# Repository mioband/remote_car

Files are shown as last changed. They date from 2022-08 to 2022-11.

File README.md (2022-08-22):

# remote_car
Данный репозиторий содержит код для модуля машинки для управления с браслета
## Ветки
В данном репозитории две основные ветки:
### main
Главная ветка со стабильной версией ПО. Здесь всегда должен быть чистый и рабочий код, а также вся документация. 
### develop
Ветка разработки. Здесь находятся тестовые и разрабатываемые версии кода.

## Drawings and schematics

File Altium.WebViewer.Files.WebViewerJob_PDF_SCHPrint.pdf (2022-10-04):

1K R8

# 0.1uFR⁹

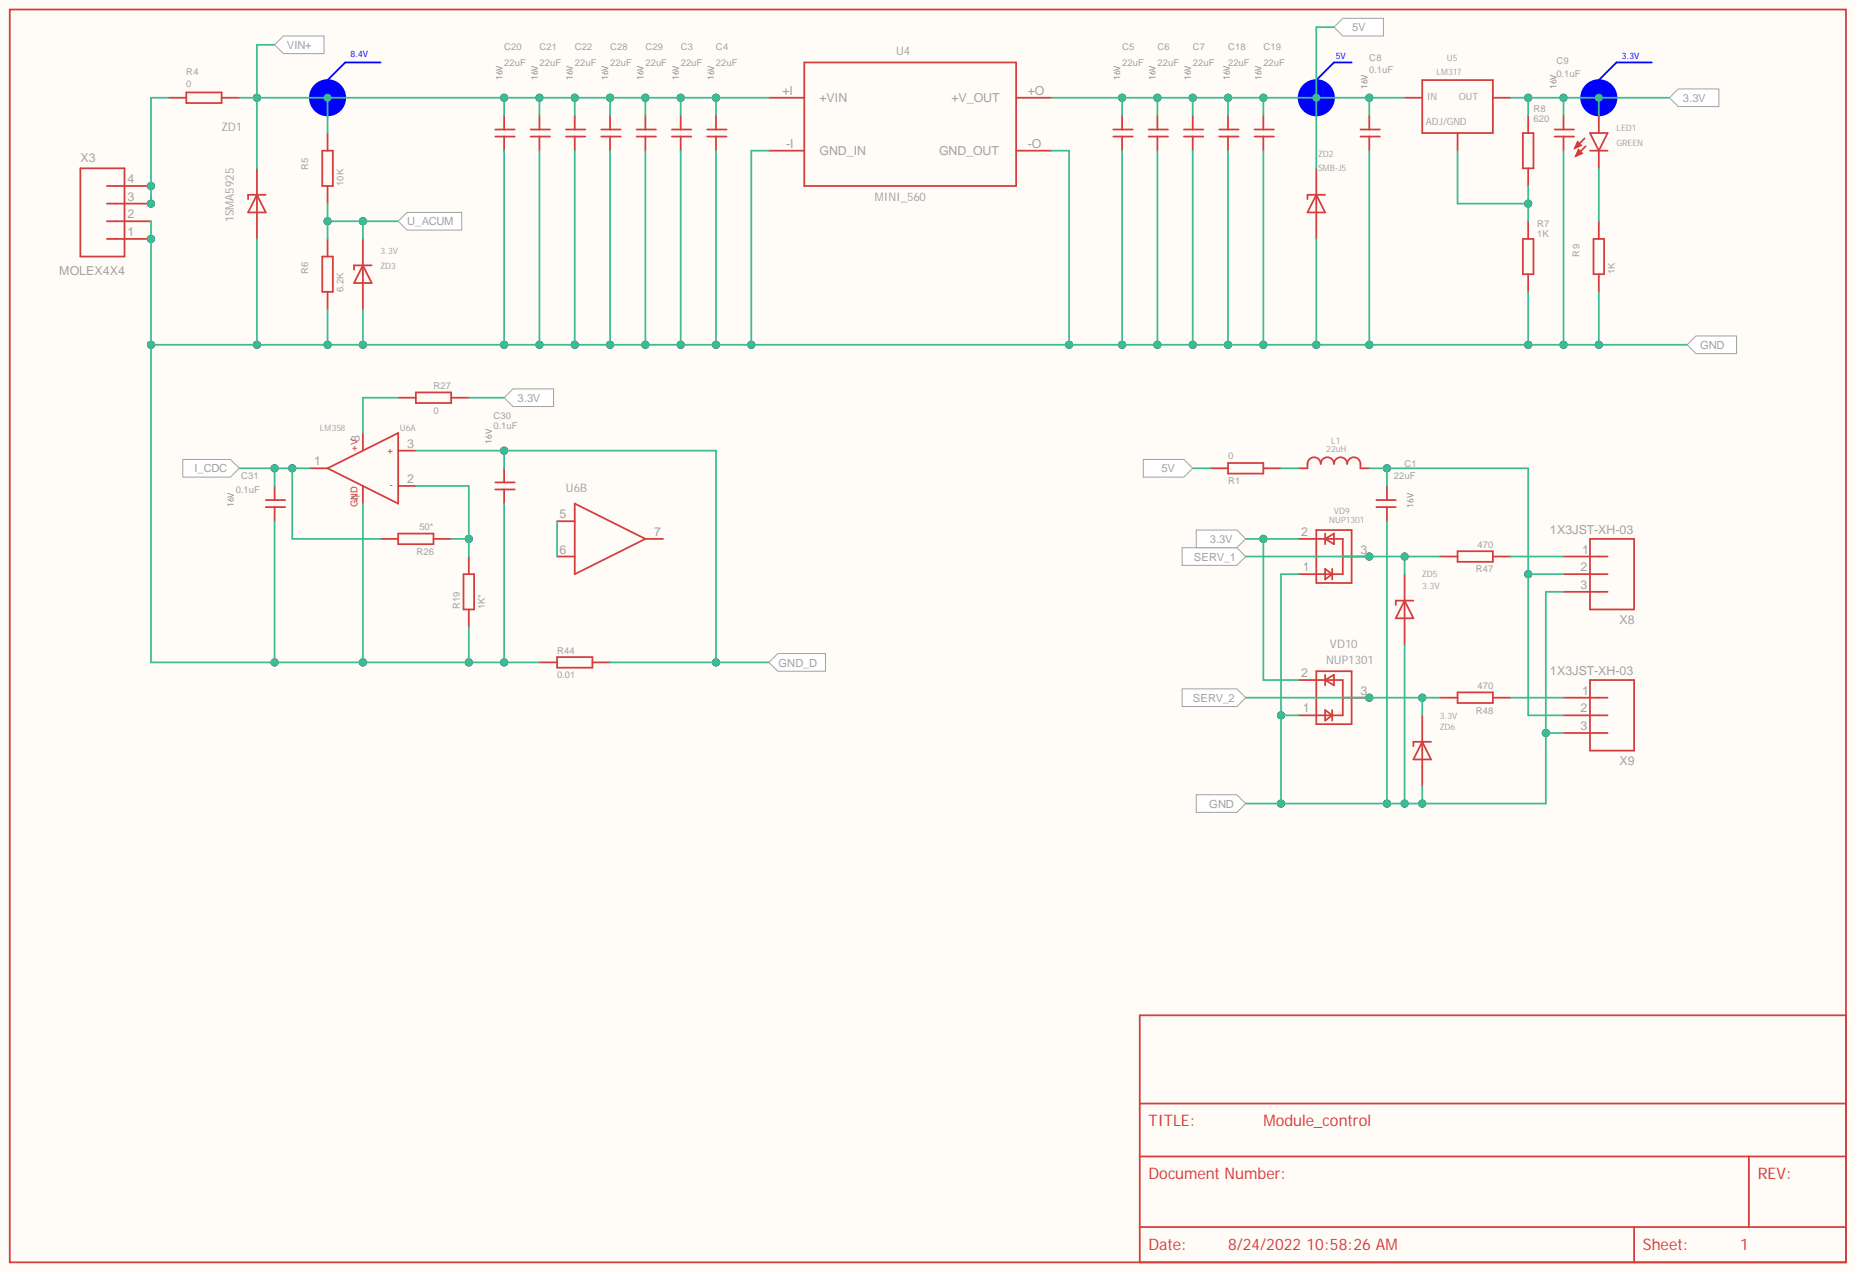
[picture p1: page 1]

: | REV:

Date: 8/24/2022 10:58:26 AM | Sheet: 1

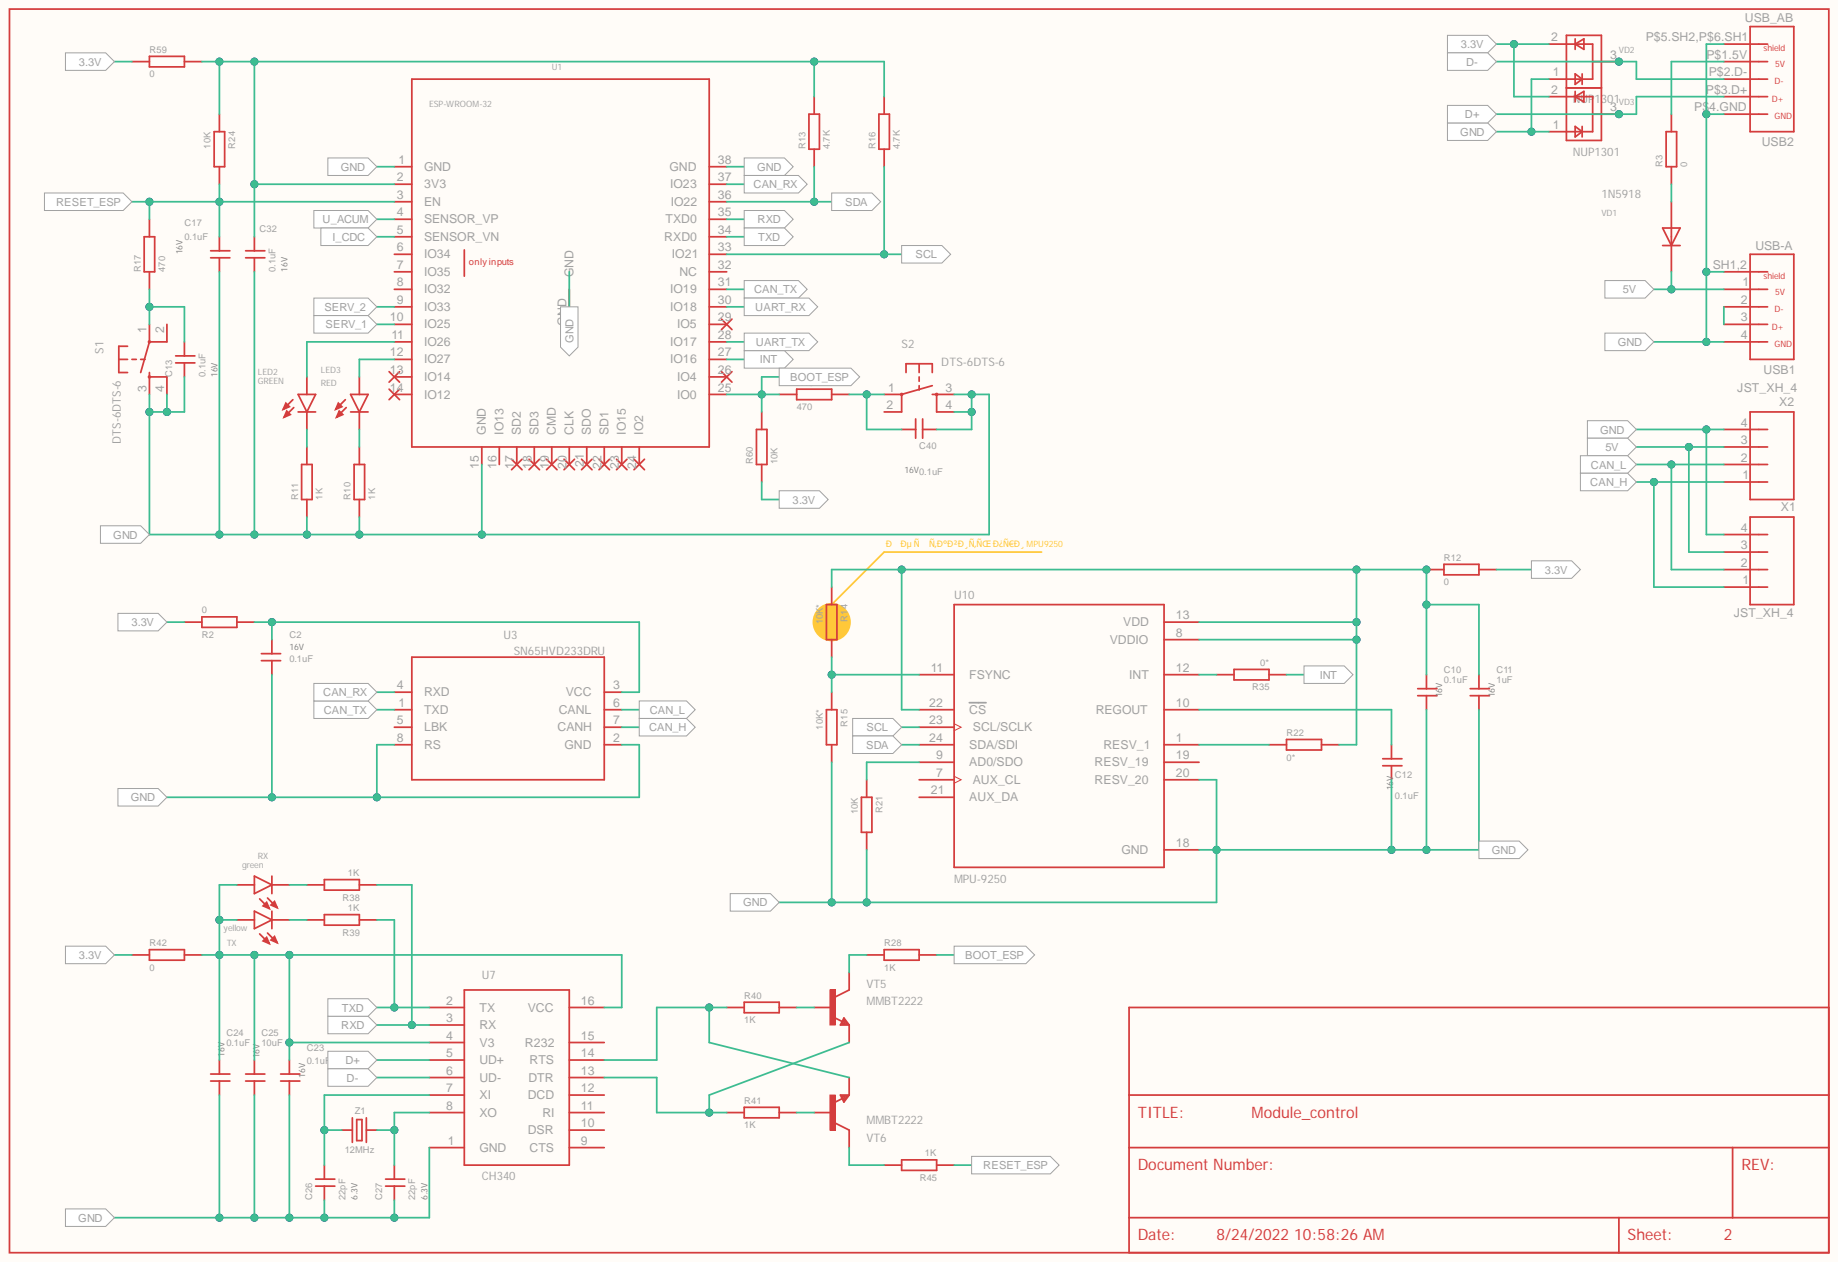
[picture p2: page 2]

IO2 24 IO15 23 SD1 22 SDO 21 CLK 20 GND GND

Document Number: | REV:

Date: 8/24/2022 10:58:26 AM | Sheet: 2

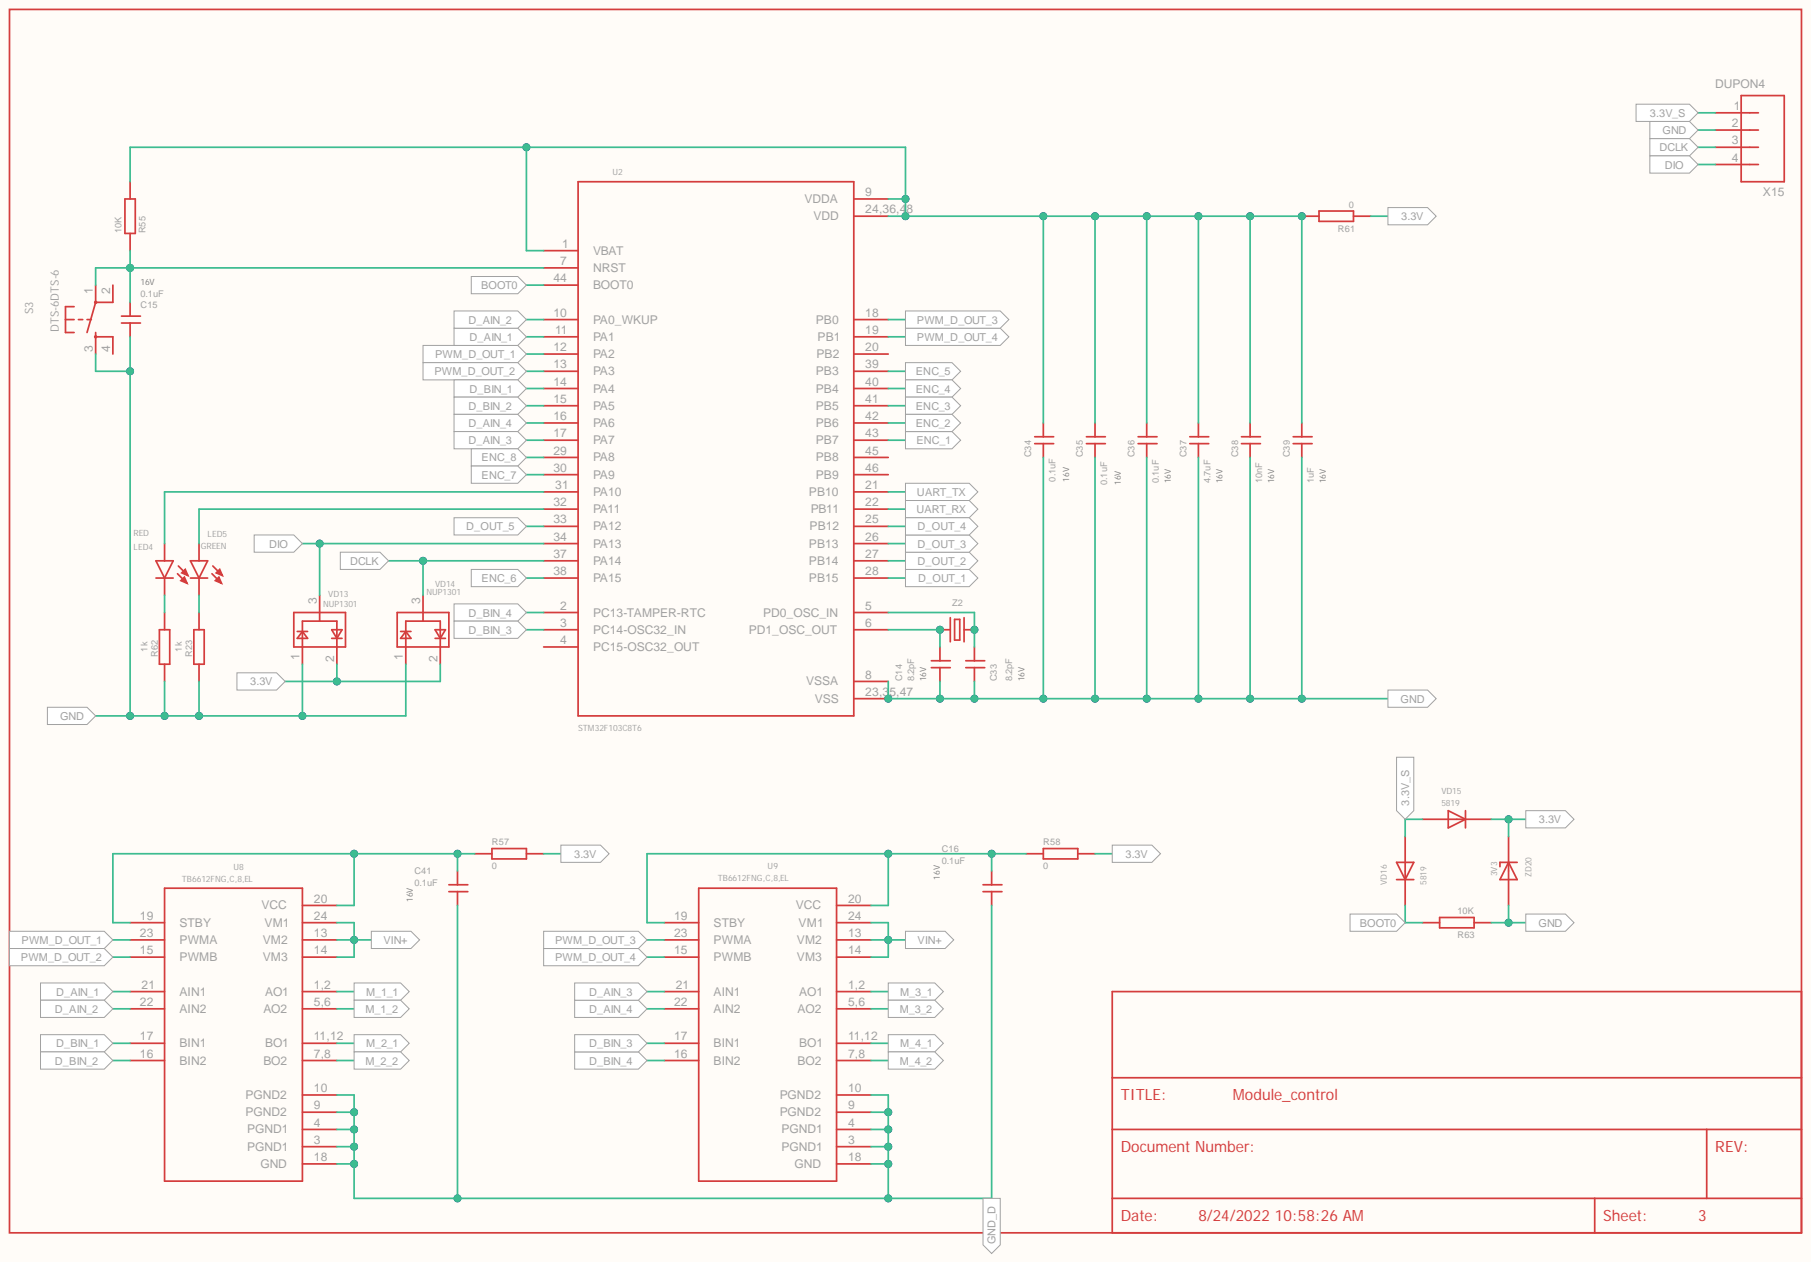
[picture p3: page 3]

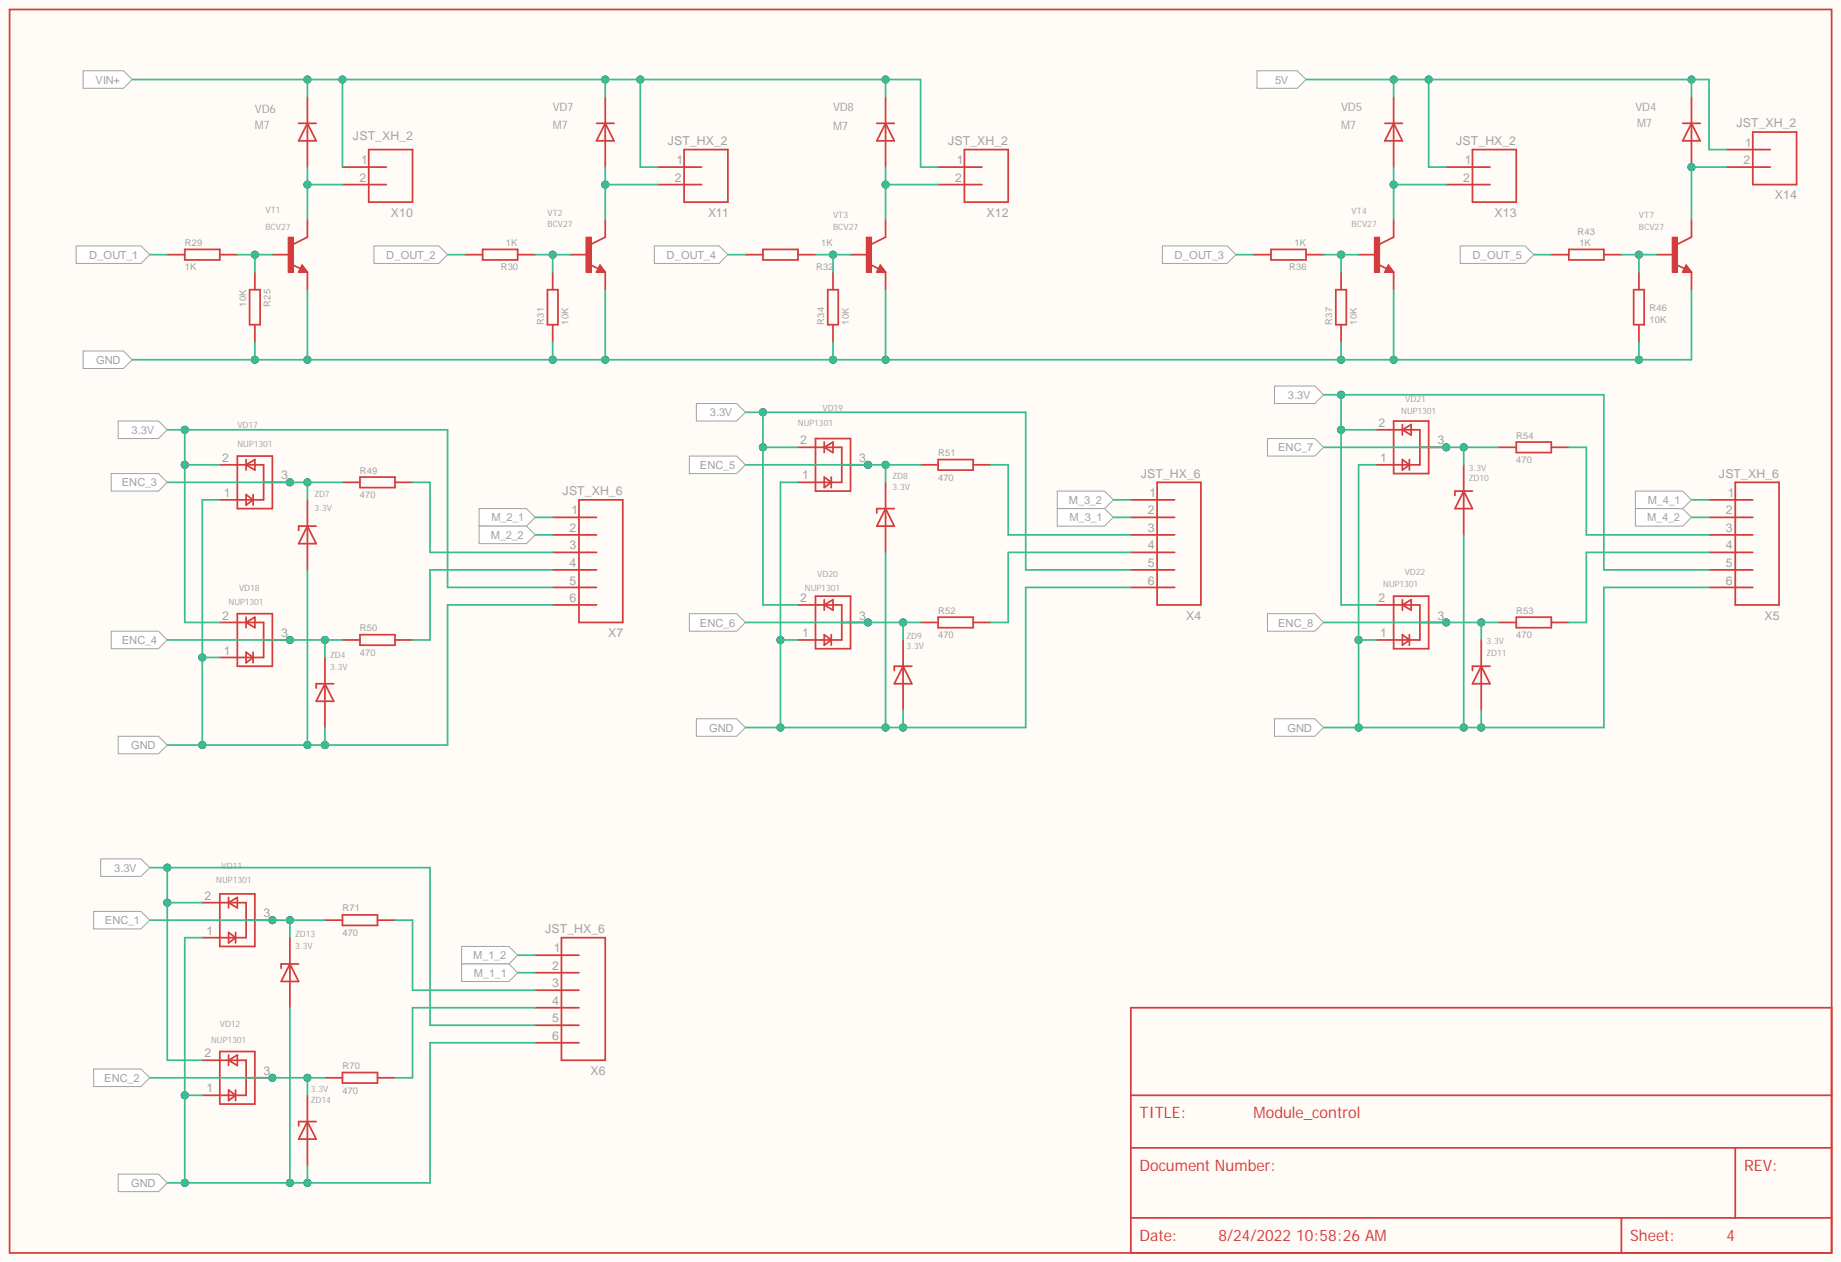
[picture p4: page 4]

Document Number: | REV:

Date: 8/24/2022 10:58:26 AM | Sheet: 4

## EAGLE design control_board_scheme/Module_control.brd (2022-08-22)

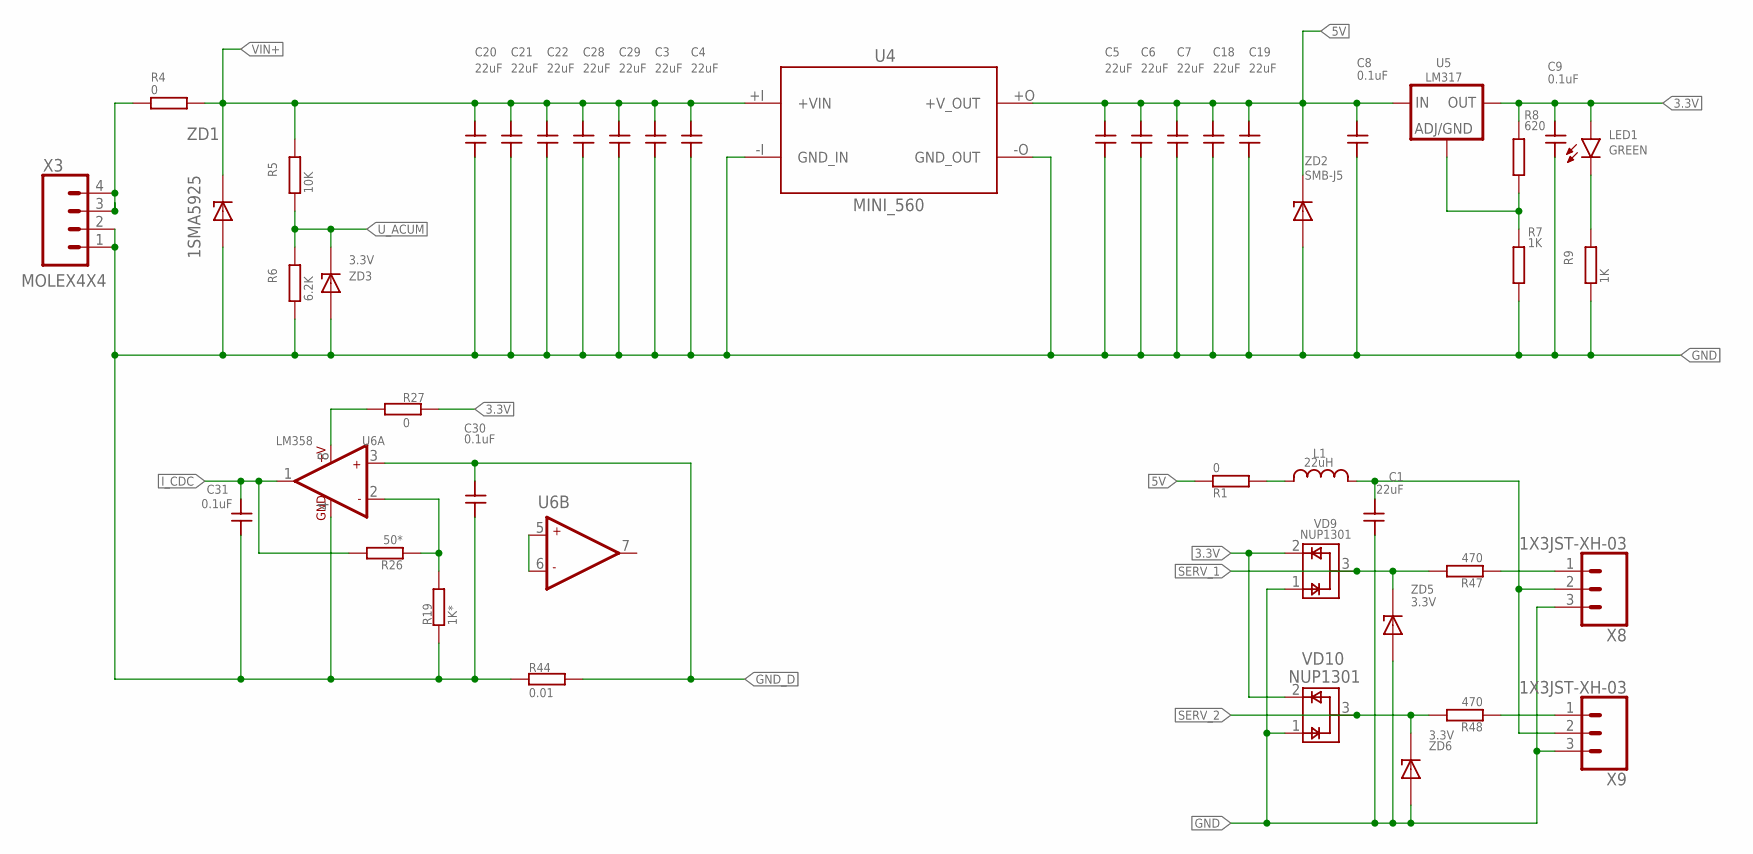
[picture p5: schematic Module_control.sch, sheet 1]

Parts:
C1, C3, C4, C5, C6, C7, C18, C19, C20, C21, C22, C28, C29: 22uF; 1206; VOLTAGE 16V
C8, C9, C30, C31: 0.1uF; 0603; VOLTAGE 16V
L1: 22uH; 0420CDMC
LED1: GREEN; 1608
R1, R27: 0; 0603
R4: 0; 2512
R5: 10K; 0603
R6: 6.2K; 0603
R7, R9: 1K; 0603
R8: 620; 0603
R19: 1K*; 0603
R26: 50*; 0603
R44: 0.01; 1206
R47, R48: 470; 0603
U4: MINI_560; MINI560_OTB
U5: LM317; D-PAK
U6: LM358; SOIC-8
VD9, VD10: NUP1301; SOT23
X3: MOLEX4X4; MOLEX-2X2U
X8, X9: 1X3JST-XH-03; JST-XH-03
ZD1: 1SMA5925; SMB
ZD2: SMB-J5; SMB
ZD3, ZD5, ZD6: 3.3V; MINIMELF

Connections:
3.3V: C9.P$2, LED1.P$2 (A), R8.P$2, R27.P$2, U5.4 (OUT), VD9.2 (VCC), VD10.2 (VCC); also elsewhere on the board
5: L1.2, R1.P$2
5V: C5.P$2, C6.P$2, C7.P$2, C8.P$2, C18.P$2, C19.P$2, R1.P$1, U4.+O (+V_OUT), U5.3 (IN), ZD2.C; also elsewhere on the board
GND: C1.P$1, C3.P$1, C4.P$1, C5.P$1, C6.P$1, C7.P$1, C8.P$1, C9.P$1, C18.P$1, C19.P$1, C20.P$1, C21.P$1, C22.P$1, C28.P$1, C29.P$1, C30.P$1, C31.P$1, R6.P$1, R7.P$2, R9.P$1, R19.P$1, R44.P$1, U4.-I (GND_IN), U4.-O (GND_OUT), U6.4 (GND), VD9.1 (GND), VD10.1 (GND), X3.1, X3.2, X8.3, X9.3, ZD1.A, ZD2.A, ZD3.A, ZD5.A, ZD6.A; also elsewhere on the board
GND_D: C30.P$2, R44.P$2, U6.3 (+IN1); also elsewhere on the board
I_CDC: C31.P$2, R26.P$2, U6.1 (OUT1); also elsewhere on the board
unnamed: R48.P$1, X9.1
unnamed: R7.P$1, R8.P$1, U5.1 (ADJ/GND)
unnamed: LED1.P$1 (C), R9.P$2
unnamed: R4.1, X3.3, X3.4
unnamed: R47.P$1, X8.1
unnamed: R19.P$2, R26.P$1, U6.2 (-IN1)
unnamed: U6.5 (+IN2), U6.6 (-IN2)
SERV_1: R47.P$2, VD9.3 (I/O), ZD5.C; also elsewhere on the board
SERV_2: R48.P$2, VD10.3 (I/O), ZD6.C; also elsewhere on the board
U_ACUM: R5.P$1, R6.P$2, ZD3.C; also elsewhere on the board
V+: R27.P$1, U6.8 (+V)
VIN+: C3.P$2, C4.P$2, C20.P$2, C21.P$2, C22.P$2, C28.P$2, C29.P$2, R4.2, R5.P$2, U4.+I (+VIN), ZD1.C; also elsewhere on the board
VSERV: C1.P$2, L1.1, X8.2, X9.2

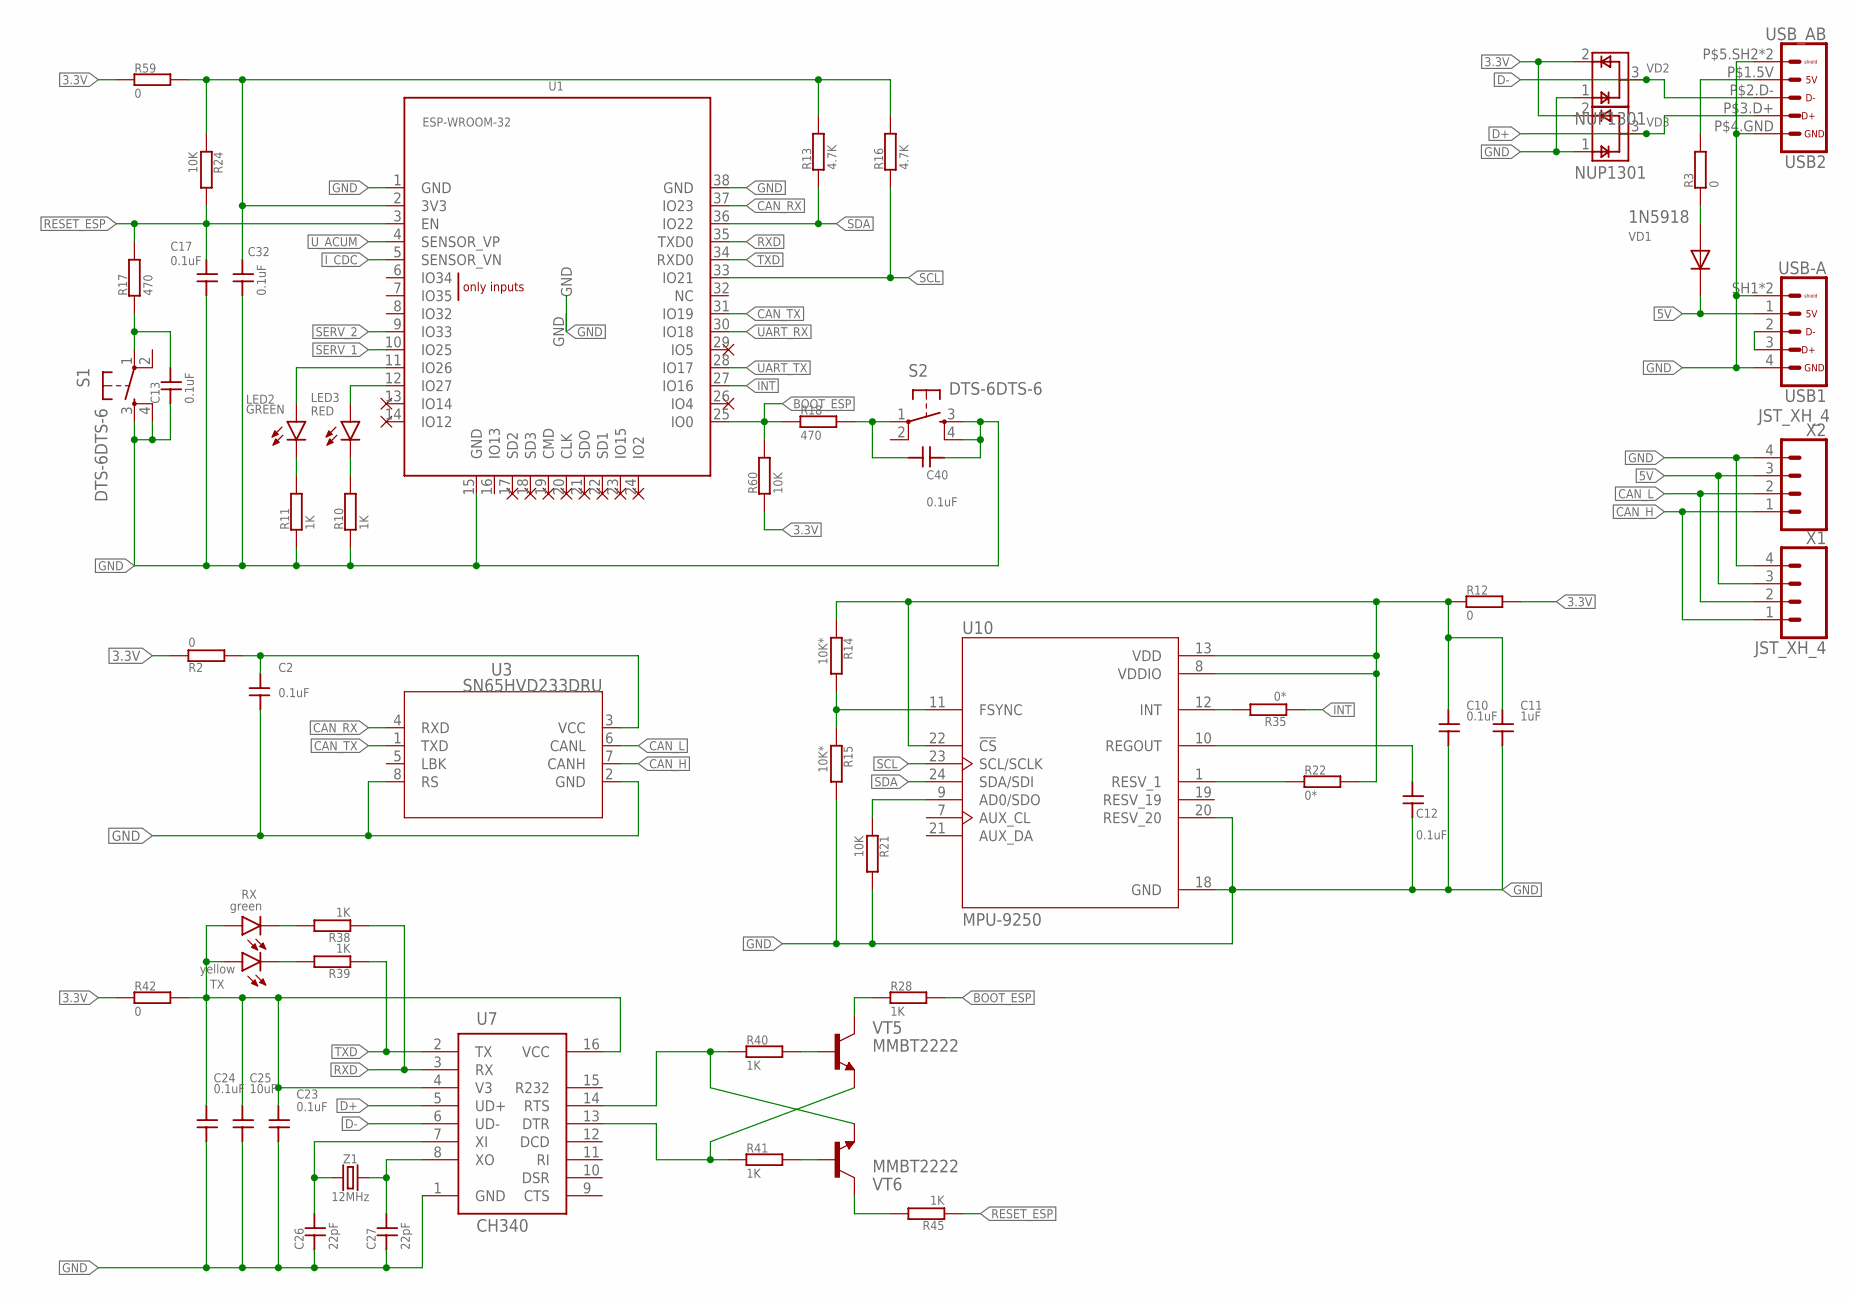
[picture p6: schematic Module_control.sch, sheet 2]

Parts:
C2, C10, C12, C13, C17, C23, C24, C32, C40: 0.1uF; 0603; VOLTAGE 16V
C11: 1uF; 0603; VOLTAGE 16V
C25: 10uF; 0603; VOLTAGE 16V
C26, C27: 22pF; 0603; VOLTAGE 6.3V
LED2: GREEN; 1608
LED3: RED; 1608
R2, R3, R12, R42, R59: 0; 0603
R10, R11, R28, R38, R39, R40, R41, R45: 1K; 0603
R13, R16: 4.7K; 0603
R14, R15: 10K*; 0603
R17, R18: 470; 0603
R21, R24, R60: 10K; 0603
R22, R35: 0*; 0603
RX: green; 2013
S1, S2: DTS-6DTS-6; DTS-6
TX: yellow; 2013
U1: ESP-WROOM-32
U3: SN65HVD233DRU; SOIC-8
U7: CH340; SOIC-16
U10: MPU-9250; QFN40P300X300X105-24N
USB1: USB-A; A-VERTICAL
USB2: USB_AB; B-VERTICAL
VD1: 1N5918; SOD123
VD2, VD3: NUP1301; SOT23
VT5, VT6: MMBT2222; SOT-23
X1, X2: JST_XH_4; JST-XH-04
Z1: 12MHz; CRYSTAL-SMD-3.2X2.5MM

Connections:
3.3V: R2.P$1, R12.P$2, R42.P$1, R59.P$1, R60.P$1, VD2.2 (VCC), VD3.2 (VCC); also elsewhere on the board
5V: USB1.1, VD1.C, X1.3, X2.3; also elsewhere on the board
+3.3: C2.P$2, R2.P$2, U3.3 (VCC)
+3V: C10.P$2, C11.P$2, R12.P$1, R14.P$1, R22.P$2, U10.8 (VDDIO), U10.13 (VDD), U10.22 (!CS)
BOOT_ESP: R18.P$1, R28.P$2, R60.P$2, U1.25 (IO0)
CAN_H: U3.7 (CANH), X1.1, X2.1
CAN_L: U3.6 (CANL), X1.2, X2.2
CAN_RX: U1.37 (IO23), U3.4 (RXD)
CAN_TX: U1.31 (IO19), U3.1 (TXD)
D+: U7.5 (UD+), USB2.P$3.D+ (3), VD3.3 (I/O)
D-: U7.6 (UD-), USB2.P$2.D- (2), VD2.3 (I/O)
DTR: R41.P$1, U7.13 (DTR), VT5.2 (E)
ESP_3.3V: C32.P$2, R13.P$2, R16.P$2, R24.P$1, R59.P$2, U1.2 (3V3)
GND: C2.P$1, C10.P$1, C11.P$1, C12.P$1, C13.P$1, C17.P$1, C23.P$1, C24.P$1, C25.P$1, C26.P$1, C27.P$1, C32.P$1, C40.P$1, R10.P$1, R11.P$1, R15.P$2, R21.P$2, S1.3, S1.4, S2.3, S2.4, U1.1 (GND), U1.15 (GND), U1.38 (GND), U1.GND, U3.2 (GND), U3.8 (RS), U7.1 (GND), U10.18 (GND), U10.20 (RESV_20), USB1.4, USB1.SH1 (SHIELD), USB1.SH2 (SHIELD), USB2.P$4.GND (4), USB2.P$5.SH2 (SHIELD), USB2.P$6.SH1 (SHIELD), VD2.1 (GND), VD3.1 (GND), X1.4, X2.4; also elsewhere on the board
INT: R35.P$1, U1.27 (IO16)
IT: R35.P$2, U10.12 (INT)
I_CDC: U1.5 (SENSOR_VN); also elsewhere on the board
unnamed: C40.P$2, R18.P$2, S2.1
unnamed: R3.P$2, USB2.P$1.5V (1)
unnamed: USB1.2, USB1.3
unnamed: R3.P$1, VD1.A
unnamed: LED2.P$2 (A), U1.11 (IO26)
unnamed: LED3.P$2 (A), U1.12 (IO27)
unnamed: LED3.P$1 (C), R10.P$2
unnamed: LED2.P$1 (C), R11.P$2
unnamed: R21.P$1, U10.9 (AD0/SDO)
unnamed: C12.P$2, U10.10 (REGOUT)
unnamed: R22.P$1, U10.1 (RESV_1)
unnamed: R38.P$2, RX.P$1 (C)
unnamed: R14.P$2, R15.P$1, U10.11 (FSYNC)
unnamed: R39.P$2, TX.P$1 (C)
unnamed: C27.P$2, U7.8 (XO), Z1.3 (2)
unnamed: C26.P$2, U7.7 (XI), Z1.1
unnamed: R40.P$2, VT5.1 (B)
unnamed: R41.P$2, VT6.1 (B)
unnamed: R28.P$1, VT5.3 (C)
unnamed: R45.P$2, VT6.3 (C)
unnamed: C13.P$2, R17.P$1, S1.1
RESET_ESP: C17.P$2, R17.P$2, R24.P$2, R45.P$1, U1.3 (EN)
RTS: R40.P$1, U7.14 (RTS), VT6.2 (E)
RXD: R38.P$1, U1.35 (TXD0), U7.3 (RX)
SCL: R16.P$1, U1.33 (IO21), U10.23 (SCL/SCLK)
SDA: R13.P$1, U1.36 (IO22), U10.24 (SDA/SDI)
SERV_1: U1.10 (IO25); also elsewhere on the board
SERV_2: U1.9 (IO33); also elsewhere on the board
TXD: R39.P$1, U1.34 (RXD0), U7.2 (TX)
UART_RX: U1.30 (IO18); also elsewhere on the board
UART_TX: U1.28 (IO17); also elsewhere on the board
U_ACUM: U1.4 (SENSOR_VP); also elsewhere on the board
VCC: C23.P$2, C24.P$2, C25.P$2, R42.P$2, RX.P$2 (A), TX.P$2 (A), U7.4 (V3), U7.16 (VCC)

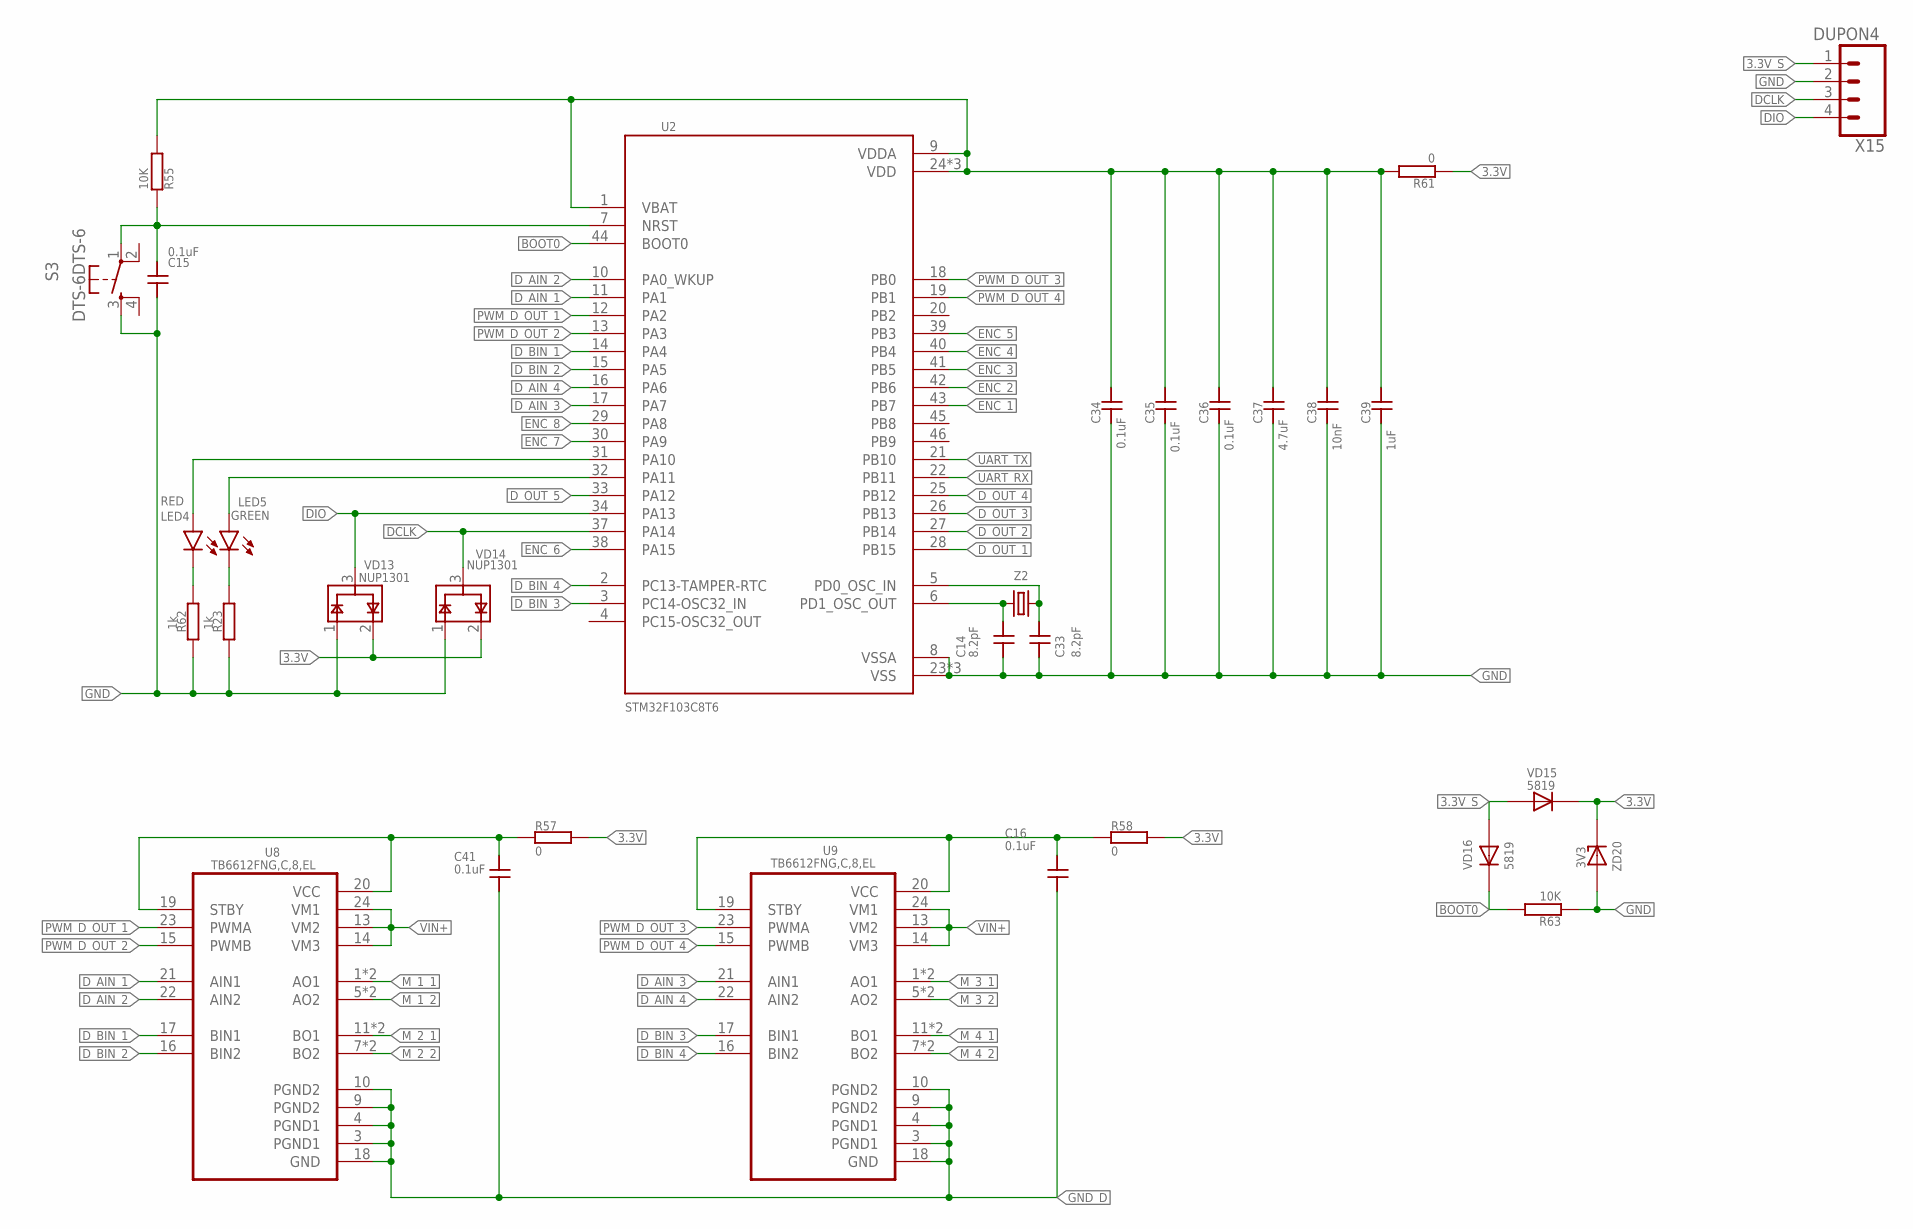
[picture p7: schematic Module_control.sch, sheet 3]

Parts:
C14, C33: 8.2pF; 0603; VOLTAGE 16V
C15, C16, C34, C35, C36, C41: 0.1uF; 0603; VOLTAGE 16V
C37: 4.7uF; 0603; VOLTAGE 16V
C38: 10nF; 0603; VOLTAGE 16V
C39: 1uF; 0603; VOLTAGE 16V
LED4: RED; 1608
LED5: GREEN; 1608
R23, R62: 1k; 0603
R55, R63: 10K; 0603
R57, R58, R61: 0; 0603
S3: DTS-6DTS-6; DTS-6
U2: STM32F103C8T6; QFP50P900X900X160-48N
U8, U9: TB6612FNG,C,8,EL; SOP65
VD13, VD14: NUP1301; SOT23
VD15, VD16: 5819; SOD123
X15: DUPON4; 1X04DUPON
Z2: 8MHz; CRYSTAL-SMD-3.2X2.5MM
ZD20: 3V3; MINIMELF

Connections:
3.3V: R57.P$2, R58.P$2, R61.P$1, VD13.2 (VCC), VD14.2 (VCC), VD15.C, ZD20.C; also elsewhere on the board
3.3V_S: VD15.A, VD16.A, X15.1
+VC: C41.P$2, R57.P$1, U8.19 (STBY), U8.20 (VCC)
BOOT0: R63.P$2, U2.44 (BOOT0), VD16.C
DCLK: U2.37 (PA14), VD14.3 (I/O), X15.3
DIO: U2.34 (PA13), VD13.3 (I/O), X15.4
D_AIN_1: U2.11 (PA1), U8.21 (AIN1)
D_AIN_2: U2.10 (PA0_WKUP), U8.22 (AIN2)
D_AIN_3: U2.17 (PA7), U9.21 (AIN1)
D_AIN_4: U2.16 (PA6), U9.22 (AIN2)
D_BIN_1: U2.14 (PA4), U8.17 (BIN1)
D_BIN_2: U2.15 (PA5), U8.16 (BIN2)
D_BIN_3: U2.3 (PC14-OSC32_IN), U9.17 (BIN1)
D_BIN_4: U2.2 (PC13-TAMPER-RTC), U9.16 (BIN2)
D_OUT_1: U2.28 (PB15); also elsewhere on the board
D_OUT_2: U2.27 (PB14); also elsewhere on the board
D_OUT_3: U2.26 (PB13); also elsewhere on the board
D_OUT_4: U2.25 (PB12); also elsewhere on the board
D_OUT_5: U2.33 (PA12); also elsewhere on the board
ENC_1: U2.43 (PB7); also elsewhere on the board
ENC_2: U2.42 (PB6); also elsewhere on the board
ENC_3: U2.41 (PB5); also elsewhere on the board
ENC_4: U2.40 (PB4); also elsewhere on the board
ENC_5: U2.39 (PB3); also elsewhere on the board
ENC_6: U2.38 (PA15); also elsewhere on the board
ENC_7: U2.30 (PA9); also elsewhere on the board
ENC_8: U2.29 (PA8); also elsewhere on the board
GND: C14.P$1, C15.P$2, C33.P$1, C34.P$1, C35.P$1, C36.P$1, C37.P$1, C38.P$1, C39.P$1, R23.P$2, R62.P$2, R63.P$1, S3.3, U2.8 (VSSA), U2.23 (VSS), U2.35 (VSS), U2.47 (VSS), VD13.1 (GND), VD14.1 (GND), X15.2, ZD20.A; also elsewhere on the board
GND_D: C16.P$1, C41.P$1, U8.3 (PGND1), U8.4 (PGND1), U8.9 (PGND2), U8.10 (PGND2), U8.18 (GND), U9.3 (PGND1), U9.4 (PGND1), U9.9 (PGND2), U9.10 (PGND2), U9.18 (GND); also elsewhere on the board
M_1_1: U8.1 (AO1), U8.2 (AO1); also elsewhere on the board
M_1_2: U8.5 (AO2), U8.6 (AO2); also elsewhere on the board
M_2_1: U8.11 (BO1), U8.12 (BO1); also elsewhere on the board
M_2_2: U8.7 (BO2), U8.8 (BO2); also elsewhere on the board
M_3_1: U9.1 (AO1), U9.2 (AO1); also elsewhere on the board
M_3_2: U9.5 (AO2), U9.6 (AO2); also elsewhere on the board
M_4_1: U9.11 (BO1), U9.12 (BO1); also elsewhere on the board
M_4_2: U9.7 (BO2), U9.8 (BO2); also elsewhere on the board
unnamed: LED4.P$1 (C), R62.P$1
unnamed: C16.P$2, R58.P$1, U9.19 (STBY), U9.20 (VCC)
unnamed: LED5.P$1 (C), R23.P$1
unnamed: LED4.P$2 (A), U2.31 (PA10)
unnamed: LED5.P$2 (A), U2.32 (PA11)
unnamed: C14.P$2, U2.6 (PD1_OSC_OUT), Z2.1
unnamed: C33.P$2, U2.5 (PD0_OSC_IN), Z2.3 (2)
NRST: C15.P$1, R55.P$1, S3.1, U2.7 (NRST)
PWM_D_OUT_1: U2.12 (PA2), U8.23 (PWMA)
PWM_D_OUT_2: U2.13 (PA3), U8.15 (PWMB)
PWM_D_OUT_3: U2.18 (PB0), U9.23 (PWMA)
PWM_D_OUT_4: U2.19 (PB1), U9.15 (PWMB)
UART_RX: U2.22 (PB11); also elsewhere on the board
UART_TX: U2.21 (PB10); also elsewhere on the board
VDD1: C34.P$2, C35.P$2, C36.P$2, C37.P$2, C38.P$2, C39.P$2, R55.P$2, R61.P$2, U2.1 (VBAT), U2.9 (VDDA), U2.24 (VDD), U2.36 (VDD), U2.48 (VDD)
VIN+: U8.13 (VM2), U8.14 (VM3), U8.24 (VM1), U9.13 (VM2), U9.14 (VM3), U9.24 (VM1); also elsewhere on the board

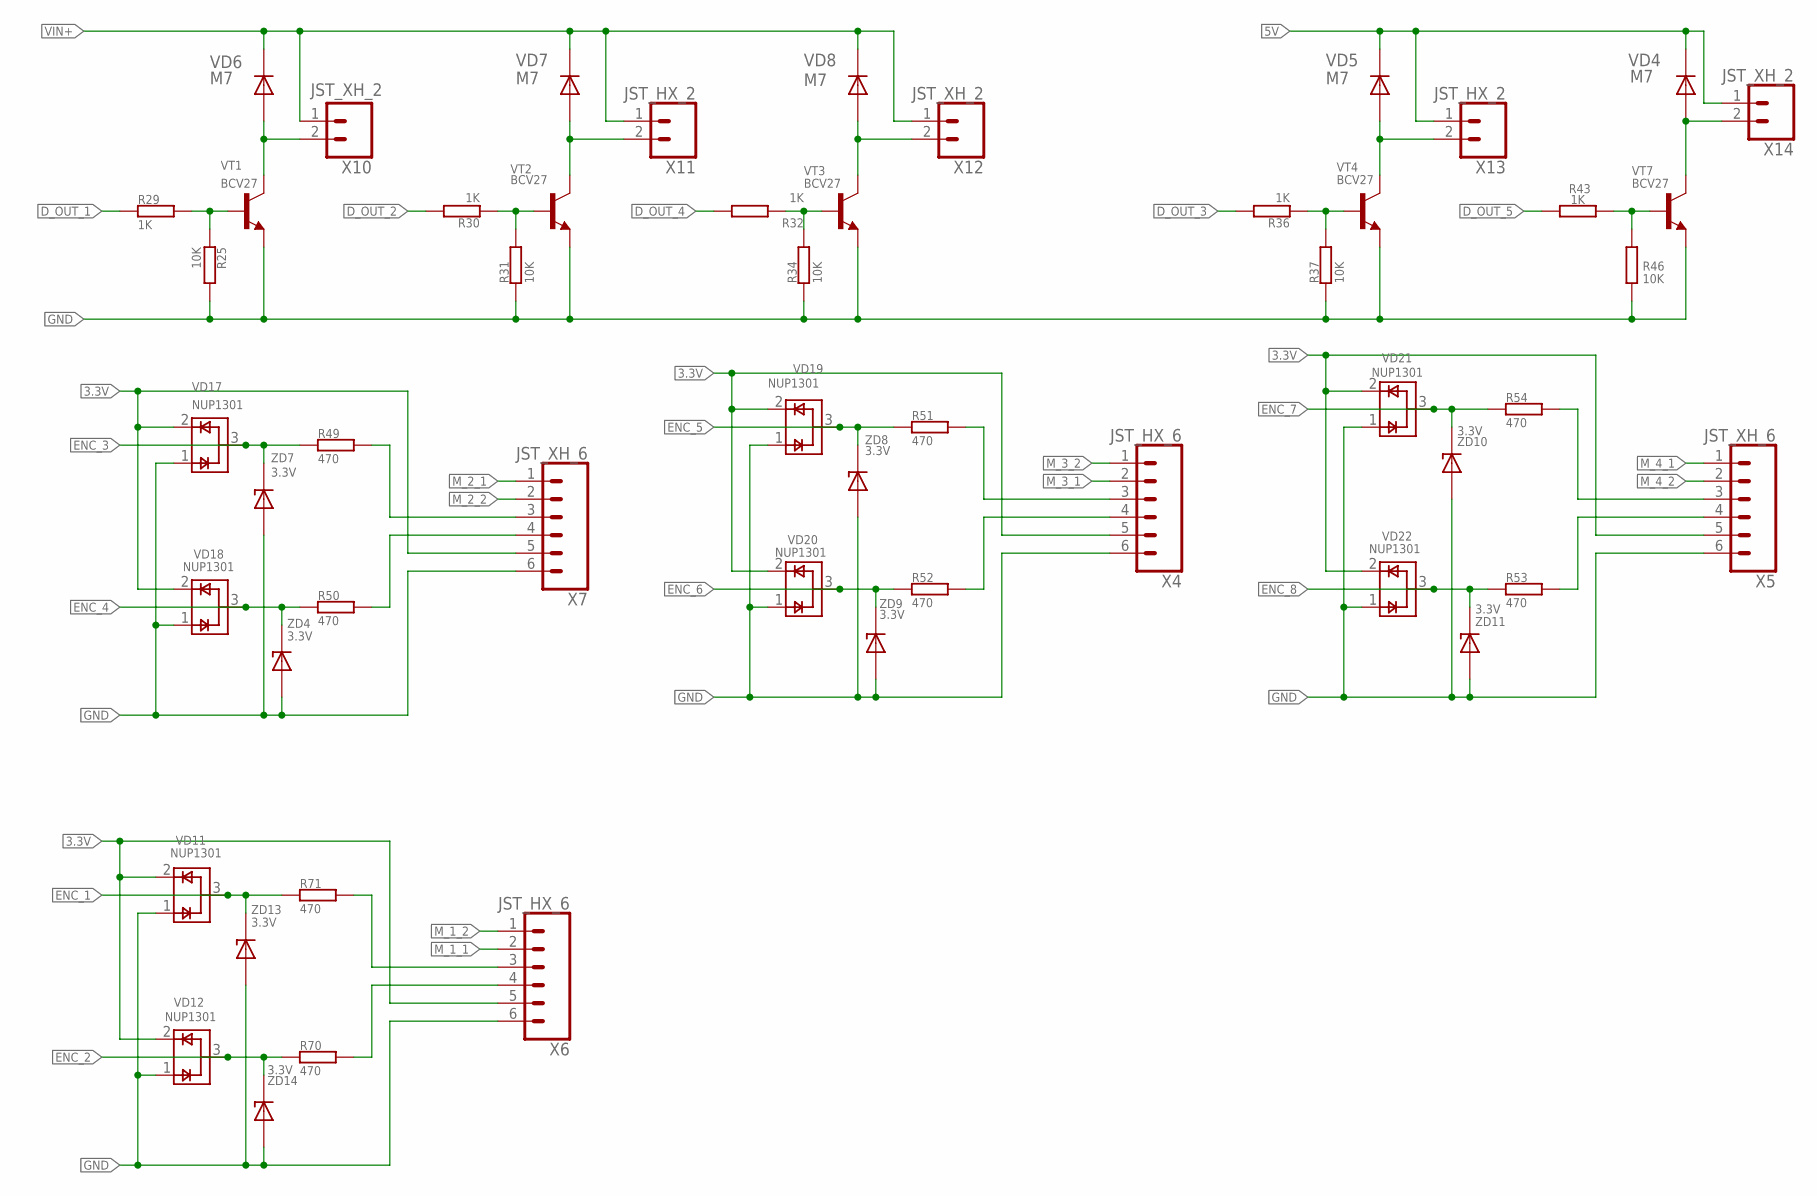
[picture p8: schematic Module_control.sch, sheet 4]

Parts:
R25, R31, R34, R37, R46: 10K; 0603
R29, R30, R32, R36, R43: 1K; 0603
R49, R50, R51, R52, R53, R54, R70, R71: 470; 0603
VD4, VD5, VD6, VD7, VD8: M7; SMA
VD11, VD12, VD17, VD18, VD19, VD20, VD21, VD22: NUP1301; SOT23
VT1, VT2, VT3, VT4, VT7: BCV27; SOT-23
X4, X6: JST_HX_6; JST-XH-06
X5, X7: JST_XH_6; JST-XH-06
X10, X12, X14: JST_XH_2; JST-XH-02
X11, X13: JST_HX_2; JST-XH-02
ZD4, ZD7, ZD8, ZD9, ZD10, ZD11, ZD13, ZD14: 3.3V; MINIMELF

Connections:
3.3V: VD11.2 (VCC), VD12.2 (VCC), VD17.2 (VCC), VD18.2 (VCC), VD19.2 (VCC), VD20.2 (VCC), VD21.2 (VCC), VD22.2 (VCC), X4.5, X5.5, X6.5, X7.5; also elsewhere on the board
5V: VD4.C, VD5.C, X13.1, X14.1; also elsewhere on the board
D_OUT_1: R29.P$1; also elsewhere on the board
D_OUT_2: R30.P$2; also elsewhere on the board
D_OUT_3: R36.P$2; also elsewhere on the board
D_OUT_4: R32.P$2; also elsewhere on the board
D_OUT_5: R43.P$2; also elsewhere on the board
ENC1: R71.P$2, X6.3
ENC2: R70.P$2, X6.4
ENC3: R49.P$2, X7.3
ENC4: R50.P$2, X7.4
ENC5: R51.P$2, X4.3
ENC6: R52.P$2, X4.4
ENC7: R54.P$2, X5.3
ENC8: R53.P$2, X5.4
ENC_1: R71.P$1, VD11.3 (I/O), ZD13.C; also elsewhere on the board
ENC_2: R70.P$1, VD12.3 (I/O), ZD14.C; also elsewhere on the board
ENC_3: R49.P$1, VD17.3 (I/O), ZD7.C; also elsewhere on the board
ENC_4: R50.P$1, VD18.3 (I/O), ZD4.C; also elsewhere on the board
ENC_5: R51.P$1, VD19.3 (I/O), ZD8.C; also elsewhere on the board
ENC_6: R52.P$1, VD20.3 (I/O), ZD9.C; also elsewhere on the board
ENC_7: R54.P$1, VD21.3 (I/O), ZD10.C; also elsewhere on the board
ENC_8: R53.P$1, VD22.3 (I/O), ZD11.C; also elsewhere on the board
GND: R25.P$2, R31.P$1, R34.P$1, R37.P$1, R46.P$1, VD11.1 (GND), VD12.1 (GND), VD17.1 (GND), VD18.1 (GND), VD19.1 (GND), VD20.1 (GND), VD21.1 (GND), VD22.1 (GND), VT1.2 (E), VT2.2 (E), VT3.2 (E), VT4.2 (E), VT7.2 (E), X4.6, X5.6, X6.6, X7.6, ZD4.A, ZD7.A, ZD8.A, ZD9.A, ZD10.A, ZD11.A, ZD13.A, ZD14.A; also elsewhere on the board
M_1_1: X6.2; also elsewhere on the board
M_1_2: X6.1; also elsewhere on the board
M_2_1: X7.1; also elsewhere on the board
M_2_2: X7.2; also elsewhere on the board
M_3_1: X4.2; also elsewhere on the board
M_3_2: X4.1; also elsewhere on the board
M_4_1: X5.1; also elsewhere on the board
M_4_2: X5.2; also elsewhere on the board
unnamed: R25.P$1, R29.P$2, VT1.1 (B)
unnamed: VD6.A, VT1.3 (C), X10.2
unnamed: R30.P$1, R31.P$2, VT2.1 (B)
unnamed: R36.P$1, R37.P$2, VT4.1 (B)
unnamed: VD7.A, VT2.3 (C), X11.2
unnamed: VD8.A, VT3.3 (C), X12.2
unnamed: VD5.A, VT4.3 (C), X13.2
unnamed: R32.P$1, R34.P$2, VT3.1 (B)
unnamed: R43.P$1, R46.P$2, VT7.1 (B)
unnamed: VD4.A, VT7.3 (C), X14.2
VIN+: VD6.C, VD7.C, VD8.C, X10.1, X11.1, X12.1; also elsewhere on the board

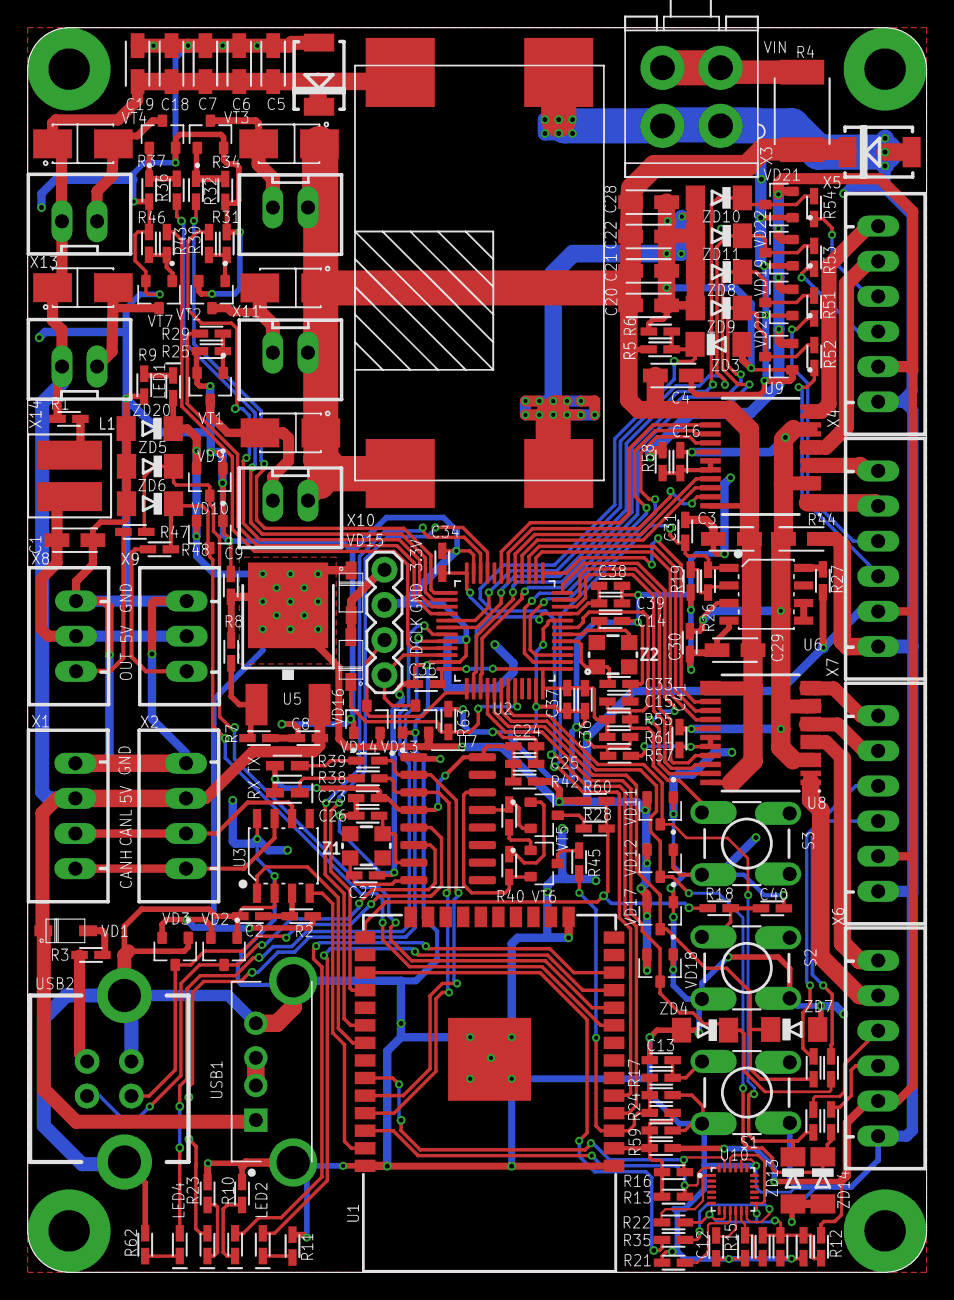
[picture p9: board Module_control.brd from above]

Board: 2 copper layers, 65.0 x 90.0 mm, 186 parts (0 on the bottom side), 127 nets.

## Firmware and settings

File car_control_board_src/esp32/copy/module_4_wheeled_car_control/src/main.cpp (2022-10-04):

// #include <Arduino.h>


// /* Analog pins */
// #define U_ACCUM     GPIO_NUM_36
// #define I_CDC       GPIO_NUM_39
// /* LEDs */
// #define LED_2       GPIO_NUM_26
// #define LED_3       GPIO_NUM_27
// /* UART pins */
// #define UART_TX     GPIO_NUM_18
// #define UART_RX     GPIO_NUM_17


// uint8_t buf_command[10];


// void led_test(void) {
//     digitalWrite(LED_2, 1);
//     digitalWrite(LED_3, 1);
//     delay(200);
//     digitalWrite(LED_2, 0);
//     digitalWrite(LED_3, 0);
//     delay(200);
// }


// void send_bytes(void) {
//     for (uint8_t i = 0; i < sizeof(buf_command); i++) {
//         Serial1.write(buf_command[i]);
//     }
// }

// void send_stop(void) {
//     Serial1.print('S');
//     for (uint8_t i = 1; i < sizeof(buf_command); i++) {
//         Serial1.write('0');
//     }
// }


// void send_beep(void) {
//     Serial1.print('Z');
//     for (uint8_t i = 1; i < sizeof(buf_command); i++) {
//         Serial1.write('0');
//     }
// }

// void send_rotate(void) {
//     Serial1.print('R');
//     for (uint8_t i = 1; i < sizeof(buf_command); i++) {
//         Serial1.write('0');
//     }
// }


// void setup() {
//     Serial.begin(115200);
//     while(!Serial);
//     Serial1.begin(115200, SERIAL_8N1, UART_RX, UART_TX, false);
//     while(!Serial1);

//     pinMode(U_ACCUM, ANALOG);
//     pinMode(I_CDC, ANALOG);
//     pinMode(LED_2, OUTPUT);
//     pinMode(LED_3, OUTPUT);
// }


// void loop() {
//     /* TEST */
//     buf_command[0] = 'B';
//     buf_command[1] = 0;
//     buf_command[2] = 50;
//     buf_command[3] = 0;
//     buf_command[4] = 50;
//     buf_command[5] = 'T';
//     buf_command[6] = 1;
//     buf_command[7] = 50;
//     buf_command[8] = 1;
//     buf_command[9] = 50;
//     send_bytes();
//     delay(5000);

//     // buf_command[2] = 1;
//     // buf_command[3] = 255;
//     // send_bytes();
//     // delay(5000);
//     // send_stop();
//     // delay(200);
    
//     // buf_command[1] = 'r';
//     // send_bytes();
//     // delay(5000);

//     // buf_command[2] = 0;
//     // buf_command[3] = 127;
//     // send_bytes();
//     // delay(5000);
//     // send_stop();
//     // delay(200);

//     // buf_command[0] = 'B';
//     // buf_command[1] = 'l';
//     // send_bytes();
//     // delay(5000);

//     // buf_command[2] = 1;
//     // buf_command[3] = 255;
//     // send_bytes();
//     // delay(5000);
//     // send_stop();
//     // delay(200);

//     // buf_command[1] = 'r';
//     // send_bytes();
//     // delay(5000);

//     // buf_command[2] = 0;
//     // buf_command[3] = 127;
//     // send_bytes();
//     // delay(5000);
//     // send_stop();
//     // delay(200);

//     // send_beep();
//     // delay(4000);
// }

#include <Arduino.h>

#include <esp_now.h>
#include <WiFi.h>

#include <Arduino.h>
#include <AsyncUDP.h>
#include <WiFi.h>
#include <WiFiAP.h>
#include <string>
#include <iterator>
#include <numeric>
#include <iterator>
#include <cstdint>

typedef struct struct_message
{
  int id;
  int x;
  int y;
  int t;
  int q;
  int w;
} struct_message;

struct_message myData;

struct_message board1;
struct_message board2;

struct_message boardsStruct[2] = {board1, board2};

///////////////////////////////////////////////////////////////
uint8_t flag = 0;

constexpr uint8_t UART_TX_PIN = GPIO_NUM_17;
constexpr uint8_t UART_RX_PIN = GPIO_NUM_16;
constexpr uint32_t UART_BAUD = 38400;

int buff_char[6];

/* Analog pins */
#define U_ACCUM     GPIO_NUM_36
#define I_CDC       GPIO_NUM_39
/* LEDs */
#define LED_2       GPIO_NUM_26
#define LED_3       GPIO_NUM_27
/* UART pins */
#define UART_TX     GPIO_NUM_18
#define UART_RX     GPIO_NUM_17


uint8_t buf_command[10];


void led_test(void) {
    digitalWrite(LED_2, 1);
    digitalWrite(LED_3, 1);
    delay(200);
    digitalWrite(LED_2, 0);
    digitalWrite(LED_3, 0);
    delay(200);
}


void send_bytes(void) {
    for (uint8_t i = 0; i < sizeof(buf_command); i++) {
        Serial1.write(buf_command[i]);
    }
}

void send_stop(void) {
    Serial1.print('S');
    for (uint8_t i = 1; i < sizeof(buf_command); i++) {
        Serial1.write('0');
    }
}


void send_beep(void) {
    Serial1.print('Z');
    for (uint8_t i = 1; i < sizeof(buf_command); i++) {
        Serial1.write('0');
    }
}

void send_rotate(void) {
    Serial1.print('R');
    for (uint8_t i = 1; i < sizeof(buf_command); i++) {
        Serial1.write('0');
    }
}

AsyncUDP udp;
String s;
///////////////////////////////////////////////////////////////

// callback function that will be executed when data is received
void OnDataRecv(const uint8_t *mac_addr, const uint8_t *incomingData, int len)
{
  char macStr[18];
  //////////////////////////////////////////////////////////////
  // Serial.print("Packet received from: ");
  snprintf(macStr, sizeof(macStr), "%02x:%02x:%02x:%02x:%02x:%02x",
           mac_addr[0], mac_addr[1], mac_addr[2], mac_addr[3], mac_addr[4], mac_addr[5]);
  // Serial.println(macStr);
  /////////////////////////////////////////////////////////////
  memcpy(&myData, incomingData, sizeof(myData));
  // Serial.printf("Board ID %u: %u bytes\n", myData.id, len);
  // Update the structures with the new incoming data
  boardsStruct[myData.id - 1].x = myData.x;
  // boardsStruct[myData.id - 1].y = myData.y;
  //  Serial.printf("x value: %d \n", boardsStruct[myData.id - 1].x);
  //  Serial.printf("y value: %d \n", boardsStruct[myData.id - 1].y);
  //  Serial.println();
  ////////////////////////////////////////////////////////////////////
  flag = 0;

  //  buff_char[0] = 'S';
  // buff_char[1] = boardsStruct[myData.id - 1].x;
  // buff_char[2] = myData.x[1];
  // buff_char[3] = myData.x[2];
  // buff_char[4] = myData.x[3];
  // buff_char[5] = myData.x[4];

  //------------------------------------------------------для майнкрафт

  // buff_char[0] = 'S';
  buff_char[0] = myData.x;
  buff_char[1] = myData.y;
  buff_char[2] = myData.t;
  buff_char[3] = myData.q;
  buff_char[4] = myData.w;
  buff_char[5] = myData.id;

  flag = 1;
  for (int i = 0; i < 6; ++i)
  {
    Serial.print(buff_char[i]);
    Serial.print(',');
  }
  Serial.println();
  Serial.println(buf_command[2]);
  Serial.println(buf_command[7]);
  ////////////////////////////////////////////////////////////////////
}

void setup()
{
  // Initialize Serial Monitor
  Serial.begin(115200);

  // Set device as a Wi-Fi Station
  WiFi.mode(WIFI_STA);

  // Init ESP-NOW
  if (esp_now_init() != ESP_OK)
  {
    Serial.println("Error initializing ESP-NOW");
    return;
  }

  // Once ESPNow is successfully Init, we will register for recv CB to
  // get recv packer info
  /////////////////////////////////////////////////////////
  Serial.begin(115200);
  Serial.println("ESPNow receiver Demo");
  esp_now_register_recv_cb(OnDataRecv);
  Serial1.begin(115200, SERIAL_8N1, UART_RX, UART_TX, false);
  while(!Serial1);

  pinMode(U_ACCUM, ANALOG);
  pinMode(I_CDC, ANALOG);
  pinMode(LED_2, OUTPUT);
  pinMode(LED_3, OUTPUT);
}

void loop()
{
    // Serial.print("ESP Board MAC Address:  ");
    // Serial.println(WiFi.macAddress());
    if (buff_char[1] > 2) {
        if (buff_char[0] == 1) {
            if (buff_char[2] == 1) {
                buf_command[0] = 'B';
                buf_command[1] = 1;
                buf_command[2] = (buff_char[1] * 10 * (1 + (1 - float((9 - (float)buff_char[3])/9)))); // left back
                buf_command[3] = 1;
                buf_command[4] = (buff_char[1] * 10 * float((9 - (float)buff_char[3])/9)); // right back
                Serial.println(buf_command[4]);
                buf_command[5] = 'T';
                buf_command[6] = 0;
                buf_command[7] = (buff_char[1] * 10 * (1 + (1 - float((9 - (float)buff_char[3])/9))));; // left forward
                buf_command[8] = 0;
                buf_command[9] = (buff_char[1] * 10 * float((9 - (float)buff_char[3])/9)); // right forward
                Serial.println(buf_command[9]);
            }
            if (buff_char[2] == 0) {
                buf_command[0] = 'B';
                buf_command[1] = 1;
                buf_command[2] = (buff_char[1] * 10 * float((9 - (float)buff_char[3])/9)); 
                buf_command[3] = 1;
                buf_command[4] = (buff_char[1] * 10 * (1 + (1 - float((9 - (float)buff_char[3])/9))));
                buf_command[5] = 'T';
                buf_command[6] = 0;
                buf_command[7] = (buff_char[1] * 10 * float((9 - (float)buff_char[3])/9));
                buf_command[8] = 0;
                buf_command[9] = (buff_char[1] * 10 * (1 + (1 - float((9 - (float)buff_char[3])/9))));
            }
        }
        if (buff_char[0] == 0) {
            buf_command[0] = 'B';
            buf_command[1] = 0;
            buf_command[2] = buff_char[1] * 10;
            buf_command[3] = 0;
            buf_command[4] = buff_char[1] * 10;
            buf_command[5] = 'T';
            buf_command[6] = 1;
            buf_command[7] = buff_char[1] * 10;
            buf_command[8] = 1;
            buf_command[9] = buff_char[1] * 10;
        }
    }
    else if (buff_char[1] <= 2) {
        if (buff_char[2] == 0) {
            buf_command[0] = 'B';
            buf_command[1] = 0;
            buf_command[2] = buff_char[3] * 10;
            buf_command[3] = 1;
            buf_command[4] = buff_char[3] * 10;
            buf_command[5] = 'T';
            buf_command[6] = 1;
            buf_command[7] = buff_char[3] * 10;
            buf_command[8] = 0;
            buf_command[9] = buff_char[3] * 10;
        }
        if (buff_char[2] == 1) {
            buf_command[0] = 'B';
            buf_command[1] = 1;
            buf_command[2] = buff_char[3] * 10;
            buf_command[3] = 0;
            buf_command[4] = buff_char[3] * 10;
            buf_command[5] = 'T';
            buf_command[6] = 0;
            buf_command[7] = buff_char[3] * 10;
            buf_command[8] = 1;
            buf_command[9] = buff_char[3] * 10;
        }
    }
    // buf_command[0] = 'B';
    // buf_command[1] = 1;
    // buf_command[2] = 200;
    // buf_command[3] = 1;
    // buf_command[4] = 50;
    // buf_command[5] = 'T';
    // buf_command[6] = 0;
    // buf_command[7] = 200;
    // buf_command[8] = 0;
    // buf_command[9] = 50;
    send_bytes();
    delay(100);
}

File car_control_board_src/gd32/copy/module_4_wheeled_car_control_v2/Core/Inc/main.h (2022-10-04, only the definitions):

#define DIG_BIN_4_Pin GPIO_PIN_13
#define DIG_BIN_4_GPIO_Port GPIOC
#define DIG_BIN_3_Pin GPIO_PIN_14
#define DIG_BIN_3_GPIO_Port GPIOC
#define DIG_AIN_2_Pin GPIO_PIN_0
#define DIG_AIN_2_GPIO_Port GPIOA
#define DIG_AIN_1_Pin GPIO_PIN_1
#define DIG_AIN_1_GPIO_Port GPIOA
#define DIG_BIN_1_Pin GPIO_PIN_4
#define DIG_BIN_1_GPIO_Port GPIOA
#define DIG_BIN_2_Pin GPIO_PIN_5
#define DIG_BIN_2_GPIO_Port GPIOA
#define DIG_AIN_4_Pin GPIO_PIN_6
#define DIG_AIN_4_GPIO_Port GPIOA
#define DIG_AIN_3_Pin GPIO_PIN_7
#define DIG_AIN_3_GPIO_Port GPIOA
#define ROTATING_Pin GPIO_PIN_12
#define ROTATING_GPIO_Port GPIOB

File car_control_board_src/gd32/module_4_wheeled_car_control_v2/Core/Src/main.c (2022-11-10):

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
/* Includes ------------------------------------------------------------------*/
#include "main.h"

/* USER CODE BEGIN Includes */
#include "car_motors_control.h" // library for controlling the motors
/* USER CODE END Includes */

/* USER CODE BEGIN PTD */
#define PWM_MAX (htim2.Init.Period * 0.88) // limitation of input signal
/* USER CODE END PTD */

/* USER CODE BEGIN PD */
/* variables for microseconds interval using */
#define DWT_CONTROL *(volatile unsigned long *)0xE0001000
#define SCB_DEMCR   *(volatile unsigned long *)0xE000EDFC
/* USER CODE END PD */

TIM_HandleTypeDef htim2;
TIM_HandleTypeDef htim3;

UART_HandleTypeDef huart3;

/* USER CODE BEGIN PV */
volatile uint8_t uart_flag = 0; // UART interrupt flag
volatile uint8_t shoot_flag = 0; // flag of the shooting process
uint8_t uart_buf[11]; // input UART buffer, data comes from ESP32 
/* USER CODE END PV */

void SystemClock_Config(void);
static void MX_GPIO_Init(void);
static void MX_TIM2_Init(void);
static void MX_TIM3_Init(void);
static void MX_USART3_UART_Init(void);
/* USER CODE BEGIN PFP */
void shoot(); // shooting func
/* USER CODE END PFP */

/* USER CODE BEGIN 0 */
/* UART input interrupt */
void HAL_UART_RxCpltCallback(UART_HandleTypeDef *huart) {
	uart_flag = 1;
	HAL_UART_Receive_IT(&huart3, (uint8_t *) uart_buf, sizeof(uart_buf));
}

/**
* @brief function for controlling the motors
* @retval None
*/
void command_accomplishing(void) {
	if (uart_buf[10] == 0) {
		shoot_flag = 1;
	}
	if ((uart_buf[10] == 1) && (shoot_flag == 1)) {
		shoot();
	}
	if (uart_buf[0] == 'B') { // change the speed of bottom motors
		move_motor(1, uart_buf[1], uart_buf[2] * PWM_MAX / 255);
		move_motor(2, uart_buf[3], uart_buf[4] * PWM_MAX / 255);
	}

	if (uart_buf[5] == 'T') { // change the speed of top motors
		move_motor(3, uart_buf[6], uart_buf[7] * PWM_MAX / 255);
		move_motor(4, uart_buf[8], uart_buf[9] * PWM_MAX / 255);
	}

//	else if (uart_buf[0] == 'R') {
//		HAL_GPIO_WritePin(ROTATING_GPIO_Port, ROTATING_Pin, 1);
//		HAL_Delay(1000);
//		HAL_GPIO_WritePin(ROTATING_GPIO_Port, ROTATING_Pin, 0);
//	}
//
//	else if (uart_buf[0] == 'S') {
//		stop_all_motors();
//	}
//
//	else if (uart_buf[0] == 'Z') {
//		TIM1 -> CCR1 = 10;
//		HAL_Delay(2000);
//		TIM1 -> CCR1 = 0;
//	}
}

void DWT_Init(void)
{
    SCB_DEMCR |= CoreDebug_DEMCR_TRCENA_Msk; // разрешаем использовать счётчик
    DWT_CONTROL |= DWT_CTRL_CYCCNTENA_Msk;   // запускаем счётчик
}

void delay_micros(uint32_t us)
{
    uint32_t us_count_tic =  us * (SystemCoreClock / 1000000); // получаем кол-во тактов за 1 мкс и умножаем на наше значение
    DWT->CYCCNT = 0U; // обнуляем счётчик
    while(DWT->CYCCNT < us_count_tic);
}

void shoot() {
  for (int i = 0; i < 300; ++i) {
	  HAL_GPIO_WritePin(ROTATING_GPIO_Port, ROTATING_Pin, GPIO_PIN_SET);
	  delay_micros(500);
	  HAL_GPIO_WritePin(ROTATING_GPIO_Port, ROTATING_Pin, GPIO_PIN_RESET);
	  delay_micros(500);
  }
  shoot_flag = 0;
}
/* USER CODE END 0 */

/**
  * @brief  The application entry point.
  * @retval int
  */
int main(void)
{
  /* MCU Configuration--------------------------------------------------------*/

  /* Reset of all peripherals, Initializes the Flash interface and the Systick. */
  HAL_Init();

  /* Configure the system clock */
  SystemClock_Config();

  /* Initialize all configured peripherals */
  MX_GPIO_Init();
  MX_TIM2_Init();
  MX_TIM3_Init();
  MX_USART3_UART_Init();
  /* USER CODE BEGIN 2 */
  DWT_Init();

//  for (int i = 0; i < 700; ++i) {
//	  HAL_GPIO_WritePin(ROTATING_GPIO_Port, ROTATING_Pin, GPIO_PIN_SET);
//	  delay_micros(500);
//	  HAL_GPIO_WritePin(ROTATING_GPIO_Port, ROTATING_Pin, GPIO_PIN_RESET);
//	  delay_micros(500);
//  }
//
//  for (int i = 0; i < 700; ++i) {
//	  HAL_GPIO_WritePin(GPIOA, GPIO_PIN_12, GPIO_PIN_SET);
//	  delay_micros(100);
//	  HAL_GPIO_WritePin(GPIOA, GPIO_PIN_12, GPIO_PIN_RESET);
//	  delay_micros(900);
//  }

//  HAL_GPIO_WritePin(GPIOA, GPIO_PIN_12, GPIO_PIN_SET);
  /* USER CODE END 2 */

  /* Infinite loop */
  /* USER CODE BEGIN WHILE */
  init_motors(); // initialization of motors structures (GPIO, timers)
  HAL_UART_Receive_IT(&huart3, (uint8_t *) uart_buf, sizeof(uart_buf)); // enable UART interrupting for receiving 11 bytes

  /*move_motor(1, 1, 100);
  HAL_Delay(2000);
  move_motor(2, 1, 100);
  HAL_Delay(2000);
  move_motor(3, 1, 100);
  HAL_Delay(2000);
  move_motor(4, 1, 100);
  HAL_Delay(2000);*/

  while (1) {
    /* if 11 bytes were received */
	  if (uart_flag) {
		  uart_flag = 0;
		  command_accomplishing(); // execute input command
	  }
    /* USER CODE END WHILE */

    /* USER CODE BEGIN 3 */
  }
  /* USER CODE END 3 */
}

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


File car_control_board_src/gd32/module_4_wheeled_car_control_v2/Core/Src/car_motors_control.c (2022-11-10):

/*
 * car_motors_control.c
 *
 *  Created on: Aug 19, 2022
 *      Author: AEra
 */
#include "car_motors_control.h"

/* timers for controlling the motors using PWM mode */
extern TIM_HandleTypeDef htim2;
extern TIM_HandleTypeDef htim3;

/* limitation of PWM signal */
#define PWM_MAX (htim2.Init.Period * 0.40)

/* motors structures */
motor_pins_s motor_1, motor_2, motor_3, motor_4;

/**
* @brief Initialization of the motor
* @retval None
*/
static void init_motor(motor_pins_s *p_motor, uint16_t dir_0_pin, GPIO_TypeDef *dir_0_prt, uint16_t dir_1_pin, GPIO_TypeDef *dir_1_prt, TIM_HandleTypeDef *p_tim, uint32_t t_channel) {
	p_motor->pin_dir_0 = dir_0_pin;
	p_motor->pin_dir_0_port = dir_0_prt;
	p_motor->pin_dir_1 = dir_1_pin;
	p_motor->pin_dir_1_port = dir_1_prt;
	p_motor->tim = p_tim;
	p_motor->tim_ch = t_channel;

	HAL_GPIO_WritePin(p_motor->pin_dir_1_port, p_motor->pin_dir_1, 0);
	HAL_GPIO_WritePin(p_motor->pin_dir_0_port, p_motor->pin_dir_0, 0);

	__HAL_TIM_SET_COMPARE(p_motor->tim, p_motor->tim_ch, 0);
	HAL_TIM_PWM_Start(p_motor->tim, p_motor->tim_ch);
}

/**
* @brief Initialization of the all motors
* @retval None
*/
#define BROWN_TANK
//#define GREEN_TANK
void init_motors(void) {
#if defined (BROWN_TANK)
	init_motor(&motor_2, DIG_AIN_1_Pin, DIG_AIN_1_GPIO_Port, DIG_AIN_2_Pin, DIG_AIN_2_GPIO_Port, &htim2, TIM_CHANNEL_3);
	init_motor(&motor_1, DIG_BIN_1_Pin, DIG_BIN_1_GPIO_Port, DIG_BIN_2_Pin, DIG_BIN_2_GPIO_Port, &htim2, TIM_CHANNEL_4);
//	init_motor(&motor_3, DIG_AIN_3_Pin, DIG_AIN_3_GPIO_Port, DIG_AIN_4_Pin, DIG_AIN_4_GPIO_Port, &htim3, TIM_CHANNEL_3);
//	init_motor(&motor_4, DIG_BIN_3_Pin, DIG_BIN_3_GPIO_Port, DIG_BIN_4_Pin, DIG_BIN_4_GPIO_Port, &htim3, TIM_CHANNEL_4);
	init_motor(&motor_3, DIG_AIN_4_Pin, DIG_AIN_4_GPIO_Port, DIG_AIN_3_Pin, DIG_AIN_3_GPIO_Port, &htim3, TIM_CHANNEL_3);
	init_motor(&motor_4, DIG_BIN_4_Pin, DIG_BIN_4_GPIO_Port, DIG_BIN_3_Pin, DIG_BIN_3_GPIO_Port, &htim3, TIM_CHANNEL_4);
#elif defined (GREEN_TANK)
	init_motor(&motor_4, DIG_AIN_2_Pin, DIG_AIN_2_GPIO_Port, DIG_AIN_1_Pin, DIG_AIN_1_GPIO_Port, &htim2, TIM_CHANNEL_3);
	init_motor(&motor_2, DIG_BIN_1_Pin, DIG_BIN_1_GPIO_Port, DIG_BIN_2_Pin, DIG_BIN_2_GPIO_Port, &htim2, TIM_CHANNEL_4);
	init_motor(&motor_3, DIG_AIN_4_Pin, DIG_AIN_4_GPIO_Port, DIG_AIN_3_Pin, DIG_AIN_3_GPIO_Port, &htim3, TIM_CHANNEL_3);
	init_motor(&motor_1, DIG_BIN_3_Pin, DIG_BIN_3_GPIO_Port, DIG_BIN_4_Pin, DIG_BIN_4_GPIO_Port, &htim3, TIM_CHANNEL_4);
#endif
}

/**
* @brief Setting direction and pwm for one of the motors 
* @param mt: pointer to motor structure
* @param dr: motor direction - either 0 or 1
* @param pulse: PWM value - from 0 to PWM_MAX
* @retval None
*/
static void set_motor_dir_pwm(motor_pins_s *mt, uint8_t dr, uint16_t pulse) {
	switch (dr) {
		case 0:
			HAL_GPIO_WritePin(mt->pin_dir_1_port, mt->pin_dir_1, 0);
			HAL_GPIO_WritePin(mt->pin_dir_0_port, mt->pin_dir_0, 1);
			break;
		case 1:
			HAL_GPIO_WritePin(mt->pin_dir_0_port, mt->pin_dir_0, 0);
			HAL_GPIO_WritePin(mt->pin_dir_1_port, mt->pin_dir_1, 1);
			break;
		default:
			HAL_GPIO_WritePin(mt->pin_dir_0_port, mt->pin_dir_0, 0);
			HAL_GPIO_WritePin(mt->pin_dir_1_port, mt->pin_dir_1, 0);
			break;
	}

	if (pulse > PWM_MAX) pulse = PWM_MAX;
	__HAL_TIM_SET_COMPARE(mt->tim, mt->tim_ch, pulse);
}

/**
* @brief Interracting with certain motor
* @param motor_num: number of the ceratin motor - from 1 to 4
* @param dir: direction for the motor: either 0 or 1
* @param pwm: output pwm value: from 0 to PWM_MAX
* @retval None
*/
void move_motor(uint8_t motor_num, uint8_t dir, uint16_t pwm) {
	switch (motor_num) {
		case 1:
			set_motor_dir_pwm(&motor_1, dir, pwm);
			break;
		case 2:
			set_motor_dir_pwm(&motor_2, dir, pwm);
			break;
		case 3:
			set_motor_dir_pwm(&motor_3, dir, pwm);
			break;
		case 4:
			set_motor_dir_pwm(&motor_4, dir, pwm);
			break;
	}
}

/**
* @brief Stopping the motor
* @param motor_num: number of the ceratin motor - from 1 to 4
* @retval None
*/
void stop_motor(uint8_t motor_num) {
	switch (motor_num) {
		case 1:
			set_motor_dir_pwm(&motor_1, 2, 0);
			break;
		case 2:
			set_motor_dir_pwm(&motor_2, 2, 0);
			break;
		case 3:
			set_motor_dir_pwm(&motor_3, 2, 0);
			break;
		case 4:
			set_motor_dir_pwm(&motor_4, 2, 0);
			break;
	}
}

/**
* @brief Stopping all the motors
* @retval None
*/
void stop_all_motors(void) {
	set_motor_dir_pwm(&motor_1, 2, 0);
	set_motor_dir_pwm(&motor_2, 2, 0);
	set_motor_dir_pwm(&motor_3, 2, 0);
	set_motor_dir_pwm(&motor_4, 2, 0);
}

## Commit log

2022-08-22 add sample stable code
2022-08-22 add sample unstable code to branch develop
2022-08-22 added control board schemes
    [Module_control.brd, Module_control.sch]
2022-08-23 added esp32 test code
2022-08-25 esp32 test code update

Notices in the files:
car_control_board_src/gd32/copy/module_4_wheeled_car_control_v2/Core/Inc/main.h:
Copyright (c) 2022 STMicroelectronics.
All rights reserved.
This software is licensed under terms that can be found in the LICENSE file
